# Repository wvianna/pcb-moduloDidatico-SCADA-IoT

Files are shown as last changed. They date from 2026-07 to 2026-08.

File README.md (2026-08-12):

# Projeto: PCB Módulo Didático SCADA/IoT

## Descrição do Projeto
Este projeto tem como objetivo fornecer uma plataforma de aprendizado para estudantes e entusiastas de automação industrial, sistemas SCADA e Internet das Coisas (IoT). A placa de circuito impresso (PCB) foi projetada para ser utilizada em laboratórios educacionais, permitindo a prática de conceitos teóricos em um ambiente controlado.

A PCB integra um **NodeMCU v2 (ESP8266)** com os seguintes componentes onboard:

- **Potenciômetro** — sinal analógico variável (simula sensor analógico)
- **Sensor DS18B20** — temperatura digital via 1-Wire
- **Driver de potência (transistor/resistência de aquecimento)** — carga controlada por PWM
- **Driver para servomotores** — canais PWM para azimute e elevação
- **Interface RS485 (MAX485)** — comunicação serial industrial half-duplex
- **Conectores para coils** — saídas digitais para relés ou buzzer
- **Conectores para entradas digitais** — contato seco ou switch onboard
- **LEDs de sinalização** — indicação visual de estado

---

> 🧩 **Projeto do firmware:** Este projeto foi desenvolvido para o firmware disponível em [github.com/wvianna/pcb-moduloDidatico-SCADA-IoT-firmware](https://github.com/wvianna/pcb-moduloDidatico-SCADA-IoT-firmware). O firmware gerencia todos os I/Os, sensores e interface RS485, implementando comunicação via **Modbus TCP/RTU**, **MQTT** e **OPC UA PubSub** — com seleção de protocolo via interface web.

---

**Autor:** William da Silva Vianna  
**Software Utilizado:** KiCad (v9 ou superior)

---

## 🧠 Visão Geral da Arquitetura

```mermaid
flowchart LR
  subgraph PCB["Placa PCB (Hardware)"]
    direction TB
    NODE[NodeMCU ESP8266]
    SEN[Sensores<br/>ADC + DS18B20]
    ATU[Atuadores<br/>Coils + PWM + Resistência]
    RS[RS485 MAX485]
    IN[Entradas Digitais]
  end

  subgraph FW["Firmware (software)"]
    REG[Modelo Interno<br/>de Registradores]
    PROT[Protocolo Ativo<br/>Modbus / MQTT / OPC UA]
    WEB[Servidor Web<br/>de Configuração]
  end

  subgraph EXT["Mundo Externo"]
    SCADA[SCADA / IHM]
    BRK[Broker MQTT]
    NRED[Node-RED]
  end

  NODE --> REG
  SEN --> REG
  REG --> ATU
  REG --> IN
  REG --> PROT
  WEB --> REG
  PROT --> SCADA
  PROT --> BRK
  PROT --> NRED
  RS -.-> SCADA
```

---

## � Pinout do NodeMCU

A imagem abaixo mostra a numeração dos pinos do **NodeMCU v2 (ESP8266)** utilizada no projeto. 
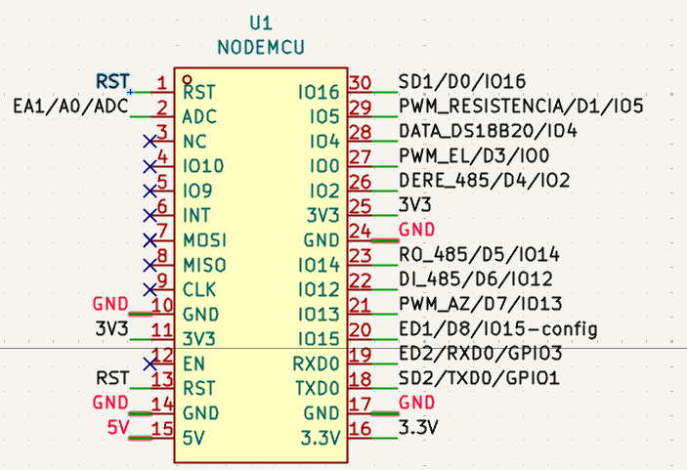
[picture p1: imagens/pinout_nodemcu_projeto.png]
Pinout NodeMCU v2 - Projeto


---

## �📋 Mapeamento de I/Os Físicos

A tabela abaixo relaciona cada funcionalidade da PCB ao pino do NodeMCU e ao registro Modbus correspondente. Este mapeamento é idêntico para todos os protocolos (Modbus, MQTT e OPC UA).

### Saídas Discretas (Coils)

| Endereço Modbus | Função | Pino NodeMCU | GPIO | Componente na PCB |
| ---: | --- | --- | --- | --- |
| 00001 | Saída discreta 1 | D0 | GPIO16 | Conector para relé/buzzer |
| 00002 | Saída discreta 2 | TX | GPIO1 | Conector para relé/buzzer |

### Entradas Discretas (Discrete Inputs)

| Endereço Modbus | Função | Pino NodeMCU | GPIO | Componente na PCB |
| ---: | --- | --- | --- | --- |
| 10001 | Entrada discreta 1 | D8 | GPIO15 | Switch onboard ou contato seco externo |
| 10002 | Entrada discreta 2 | RX | GPIO3 | Switch onboard ou contato seco externo |

> **Nota:** A entrada discreta 1 (ED1 / D8) também funciona como *boot pin* para forçar o modo de setup — basta colocá-la em nível baixo e reiniciar a placa.

### Entradas Analógicas (Input Registers)

| Endereço Modbus | Função | Pino NodeMCU | Faixa | Componente na PCB |
| ---: | --- | --- | ---: | --- |
| 30001 | ADC (potenciômetro) | A0 | 0..1023 | Potenciômetro onboard |
| 30002 | DS18B20 (temperatura) | D2 / GPIO4 | 0..1250 (x10 °C) | Sensor DS18B20 onboard |

### Saídas PWM (Holding Registers)

| Endereço Modbus | Função | Pino NodeMCU | GPIO | Faixa | Componente na PCB |
| ---: | --- | --- | --- | ---: | --- |
| 40001 | PWM azimute | D7 | GPIO13 | 0..1023 | Driver para servomotor |
| 40002 | PWM elevação | D3 | GPIO0 | 0..1023 | Driver para servomotor |
| 40003 | PWM resistência de aquecimento | D1 | GPIO5 | 0..1023 | Transistor + resistor de aquecimento onboard |

### Interface RS485 (Modbus RTU)

| Sinal MAX485 | Pino NodeMCU | GPIO |
| --- | --- | --- |
| RO (receptor) | D5 | GPIO14 |
| DI (driver) | D6 | GPIO12 |
| DE + RE (direção) | D4 | GPIO2 |

---
TIPO       |     DEVICE     | RANGE  |MODBUS
SD1        |BUZZER - PONTE H| 0 1    |COIL 00001
SD2        |RELE - PONTE H  | 0 1    |COIL 00002
PWM1       |SERVO - AZIMUTE | 0~1023 |H.R. 40001
PWM2       |SERVO - ELEVAÇÃO| 0~1023 |H.R. 40002
PMW3       |RESISTÊNCIA     | 0~1023 |H.R. 40003
ED1        |SW SECO - SETUP | 0 1    |D.I. 10001
ED2        |SW SECO         | 0 1    |D.I. 10002
EA0        |POTENCIÔMETRO   | 0~1023 |I.R. 30001
TEMPERATURA|DS18B20         | oC X 10|I.R. 30002
---

## 🔌 Diagrama de Blocos da PCB

```mermaid
flowchart TD
  subgraph PCB["PCB Módulo Didático SCADA/IoT"]
    MCU[NodeMCU ESP8266]

    subgraph ENTRADAS["Entradas"]
      POTE[Potenciômetro<br/>A0 / ADC]
      DS18[DS18B20<br/>D2 / 1-Wire]
      SW1[Switch ED1<br/>D8 / GPIO15]
      SW2[Switch ED2<br/>RX / GPIO3]
    end

    subgraph SAIDAS["Saídas"]
      C1[Coil 1<br/>D0 / GPIO16]
      C2[Coil 2<br/>TX / GPIO1]
      SRV1[Servo Azimute<br/>D7 / PWM]
      SRV2[Servo Elevação<br/>D3 / PWM]
      AQUE[Resistência<br/>D1 / PWM]
    end

    subgraph COMUM["Comunicação"]
      RS485[MAX485<br/>RS485 Half-Duplex]
    end

    subgraph SINAL["Sinalização"]
      LED[LED Config<br/>D4 / GPIO2]
    end

    MCU --- ENTRADAS
    MCU --- SAIDAS
    MCU --- RS485
    MCU --- SINAL
  end
```

---

## ⚡ Especificações Elétricas

| Parâmetro | Valor |
| --- | --- |
| Alimentação da placa | 5V DC (via USB ou conector) |
| Regulador onboard | 3,3V para o NodeMCU |
| Nível lógico dos GPIOs | 3,3V |
| Corrente máxima por GPIO | ~12 mA (com resistor de limitação) |
| Tensão no barramento RS485 | Diferencial (A/B) |
| Temperatura do DS18B20 | -55°C a +125°C |
| Faixa do ADC | 0..3,3V (10 bits, 0..1023) |

---

## 💻 Necessidade de Firmware

> ⚠️ **Nota Importante:** Este hardware **não é puramente analógico**. A placa foi projetada ao redor de uma arquitetura programável — o circuito impresso isolado não desempenha nenhuma função sem o respectivo **firmware**.

O firmware disponível em [pcb-moduloDidatico-SCADA-IoT-firmware](https://github.com/wvianna/pcb-moduloDidatico-SCADA-IoT-firmware) implementa:

1. **Inicialização (Setup):** Configuração dos registradores, direção dos pinos de I/O e taxas de transmissão dos barramentos.
2. **Loop principal cooperativo:** Leitura cíclica de sensores, atualização do modelo interno de registradores e aplicação nas saídas físicas — sem uso de `delay()` bloqueante.
3. **Servidor web de configuração:** Interface para definir SSID, IP, protocolo ativo (Modbus/MQTT/OPC UA) e parâmetros de comunicação, acessível via modo AP.
4. **Pilhas de comunicação:** Modbus TCP (porta 502), Modbus RTU (RS485), MQTT (PubSubClient) e OPC UA PubSub sobre MQTT.
5. **Persistência em LittleFS:** Configuração salva em arquivo texto na flash, com validação e fallback para valores padrão.

---

## 📁 Estrutura de Arquivos no Repositório

```text
├── esquema.pdf             # Diagrama esquemático exportado para leitura
├── meu-projeto.kicad_pro   # Arquivo de gerenciamento do projeto KiCad
├── meu-projeto.kicad_sch   # Folha do desenho esquemático
├── meu-projeto.kicad_pcb   # Layout da placa de circuito impresso
├── docs/
│   ├── mapeamentopinosmb.txt  # Mapa de pinos em formato CSV
│   └── requisitos.txt         # Requisitos elétricos e funcionais
├── firmware/                  # Submódulo do firmware
└── .gitignore              # Filtro de arquivos temporários do KiCad
```

---

## 🔗 Links Relacionados

| Recurso | Link |
| --- | --- |
| Repositório do firmware | [github.com/wvianna/pcb-moduloDidatico-SCADA-IoT-firmware](https://github.com/wvianna/pcb-moduloDidatico-SCADA-IoT-firmware) |
| Documentação do firmware | README do firmware |
| Esquema elétrico | `esquema.pdf` neste repositório |
| Mapa de pinos (CSV) | `docs/mapeamentopinosmb.txt` |

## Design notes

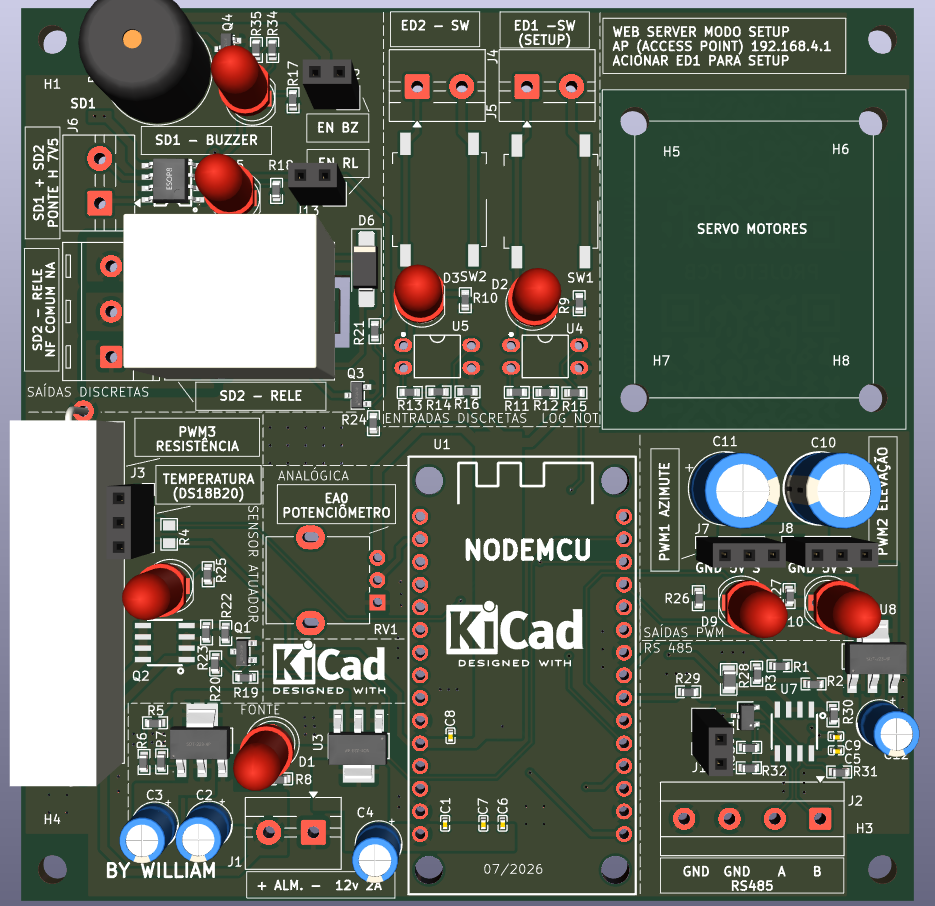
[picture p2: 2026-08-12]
imagens/pcbFront.png

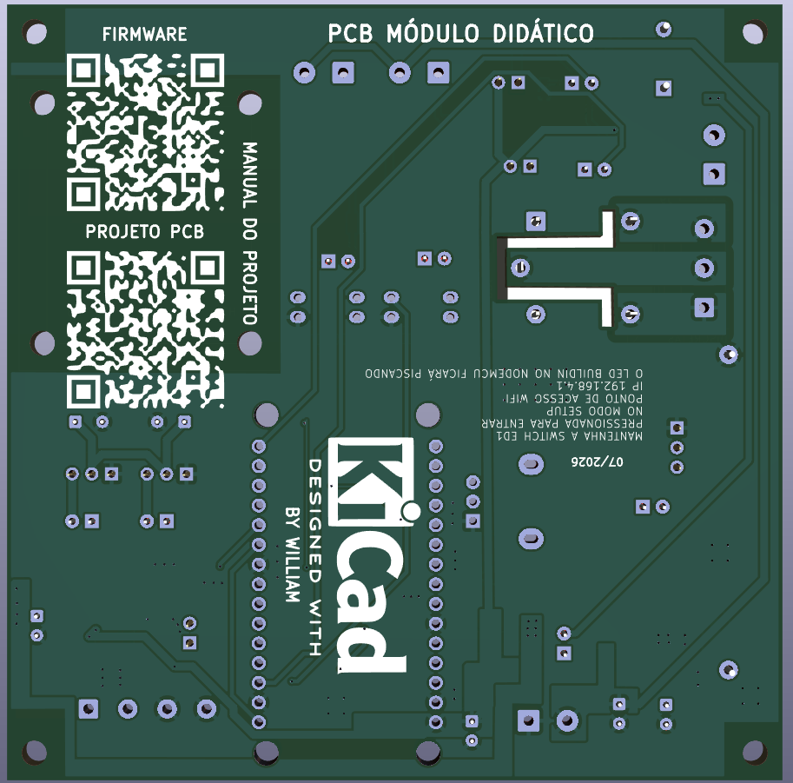
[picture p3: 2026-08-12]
imagens/pcbBack.png

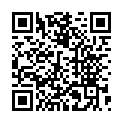
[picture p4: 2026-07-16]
imagens/qrfirmware.png

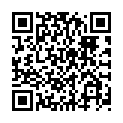
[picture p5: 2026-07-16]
imagens/qrpcb.png

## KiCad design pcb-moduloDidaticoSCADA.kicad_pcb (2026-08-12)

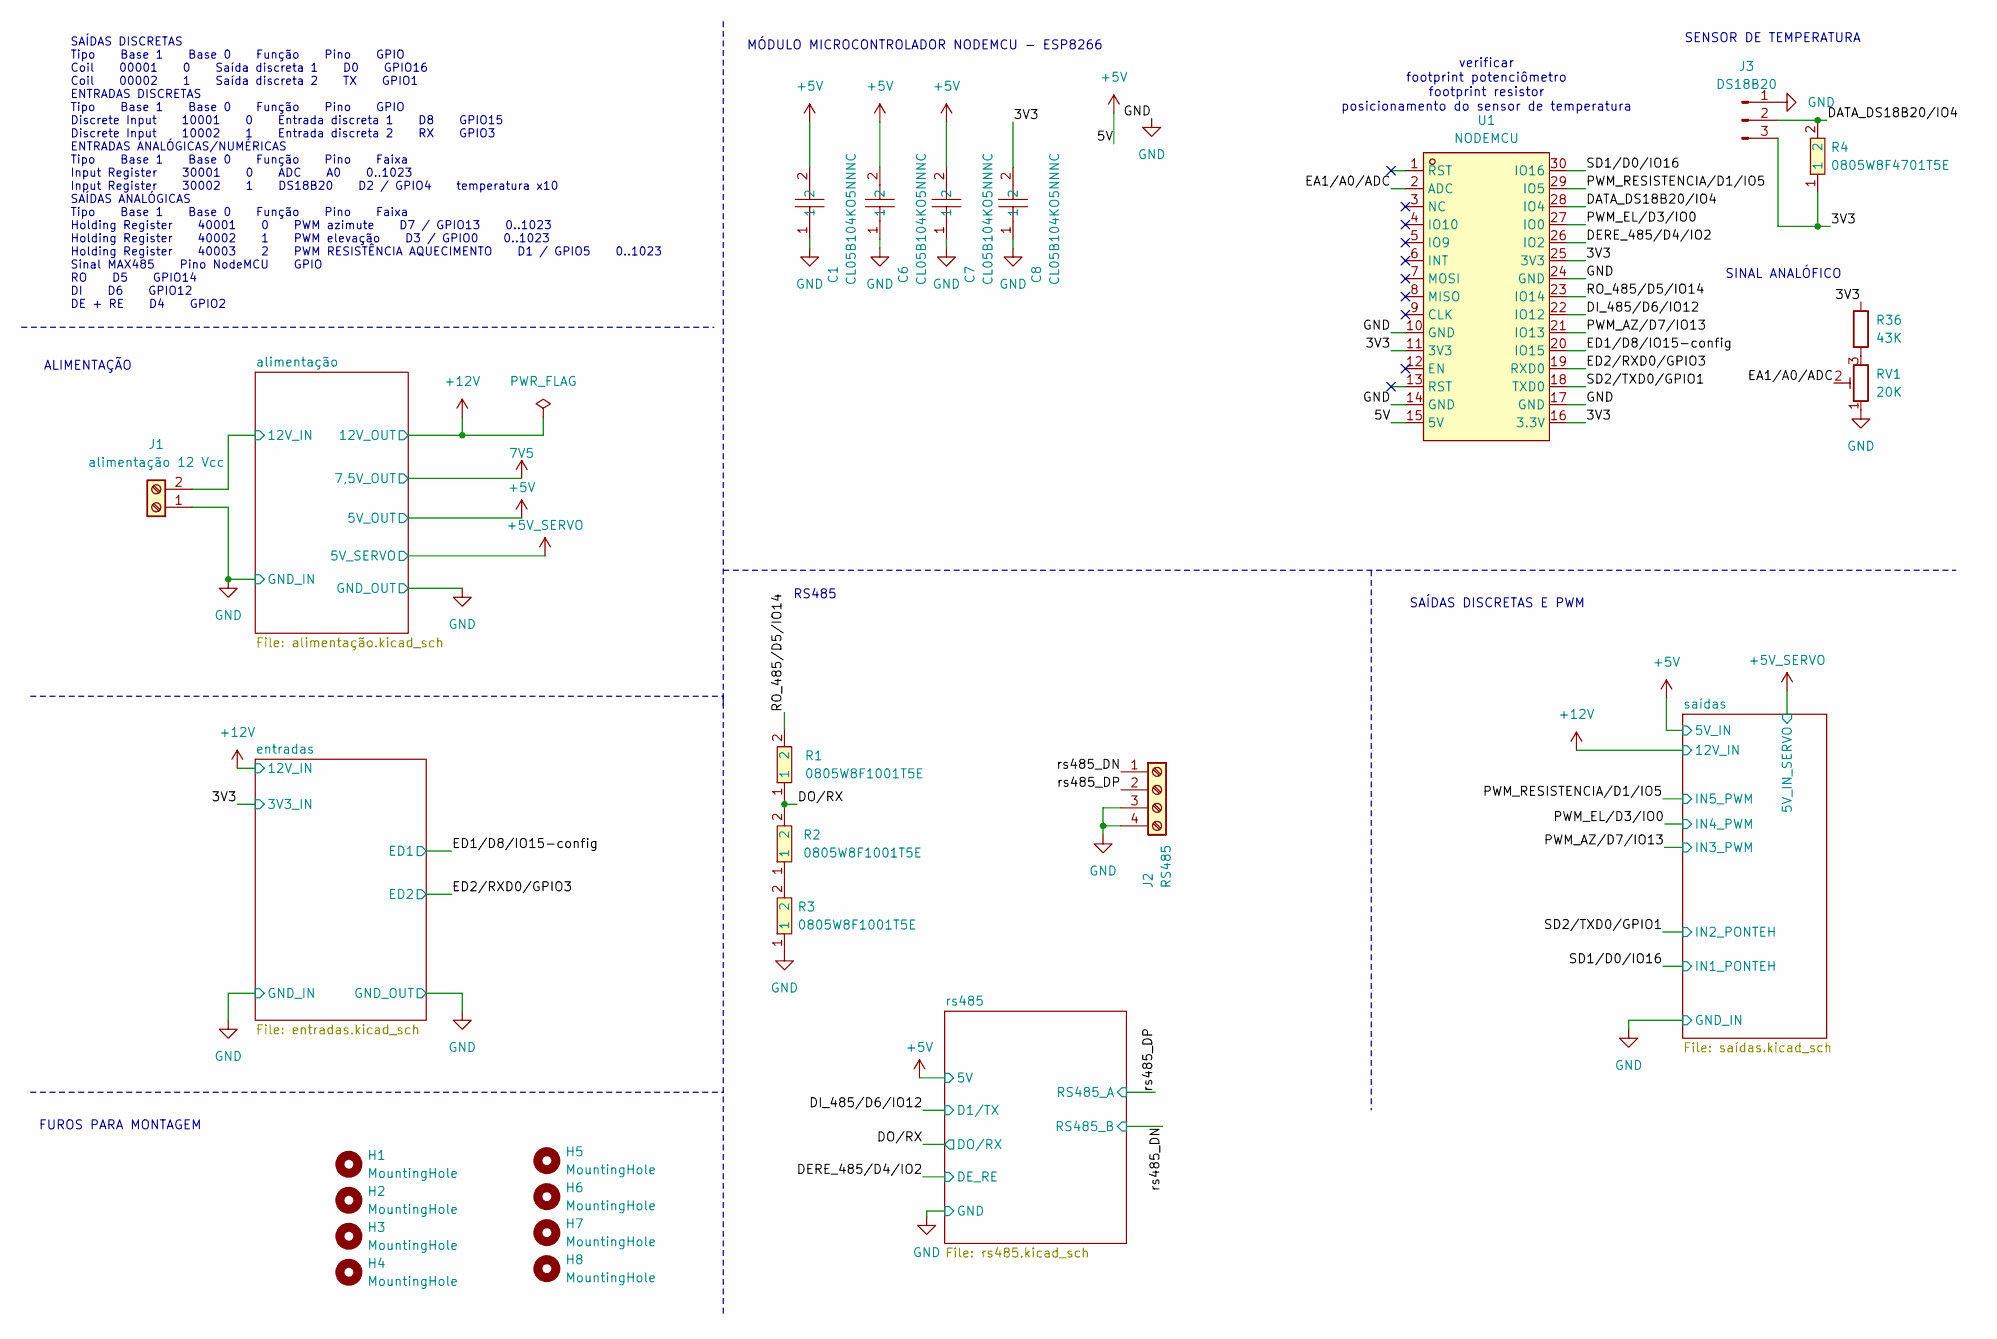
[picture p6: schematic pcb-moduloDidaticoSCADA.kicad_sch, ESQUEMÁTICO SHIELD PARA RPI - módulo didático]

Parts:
C1, C6, C7, C8: CL05B104KO5NNNC; C0402; MPN CL05B104KO5NNNC; LCSC Part C1525
H1, H2, H3, H4, H5, H6, H7, H8: MountingHole; MountingHole_3.2mm_M3
J1: alimentação 12 Vcc; TerminalBlock_MaiXu_MX126-5.0-02P_1x02_P5.00mm
J2: RS485; TerminalBlock_MetzConnect_Type101_RT01604HBWC_1x04_P5.08mm_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
J3: DS18B20; PinSocket_1x03_P2.54mm_Vertical
R1, R2, R3: 0805W8F1001T5E; R0805; MPN 0805W8F1001T5E; LCSC Part C17513
R4: 0805W8F4701T5E; R0805; LCSC Part C17673
R36: 43K; R_0805_2012Metric_Pad1.20x1.40mm_HandSolder
RV1: 20K; Potentiometer_Alpha_RD901F-40-00D_Single_Vertical
U1: NODEMCU; COMM-TH_NODEMCU-12F; MPN NODEMCU(12F); LCSC Part C2764098

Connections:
+5V: C1.2, C6.2, C7.2, U1.15 (5V); also elsewhere on the board
+12V: J1.2; also elsewhere on the board
/3V3: C8.2, J3.3, R4.1, R36.1, U1.11 (3V3), U1.16 (3.3V), U1.25 (3V3); also elsewhere on the board
/DATA_DS18B20/IO4: J3.2, R4.2, U1.28 (IO4)
/DERE_485/D4/IO2: U1.26 (IO2); also elsewhere on the board
/DI_485/D6/IO12: U1.22 (IO12); also elsewhere on the board
/DO/RX: R1.1, R2.2; also elsewhere on the board
/EA1/A0/ADC: RV1.2, U1.2 (ADC)
/ED1/D8/IO15-config: U1.20 (IO15); also elsewhere on the board
/ED2/RXD0/GPIO3: U1.19 (RXD0); also elsewhere on the board
/PWM_AZ/D7/IO13: U1.21 (IO13); also elsewhere on the board
/PWM_EL/D3/IO0: U1.27 (IO0); also elsewhere on the board
/PWM_RESISTENCIA/D1/IO5: U1.29 (IO5); also elsewhere on the board
/RO_485/D5/IO14: R1.2, U1.23 (IO14)
/SD1/D0/IO16: U1.30 (IO16); also elsewhere on the board
/SD2/TXD0/GPIO1: U1.18 (TXD0); also elsewhere on the board
/rs485_DN: J2.1; also elsewhere on the board
/rs485_DP: J2.2; also elsewhere on the board
GND: C1.1, C6.1, C7.1, C8.1, J1.1, J2.3, J2.4, J3.1, R3.1, RV1.1, U1.10 (GND), U1.14 (GND), U1.17 (GND), U1.24 (GND); also elsewhere on the board
unnamed: R2.1, R3.2
unnamed: R36.2, RV1.3

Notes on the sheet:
SENSOR DE TEMPERATURA
MÓDULO MICROCONTROLADOR NODEMCU - ESP8266
FUROS PARA MONTAGEM
SINAL ANALÓFICO
verificar footprint potenciômetro footprint resistor posicionamento do sensor de temperatura
ALIMENTAÇÃO
SAÍDAS DISCRETAS E PWM
RS485
SAÍDAS DISCRETAS Tipo Base 1 Base 0 Função Pino GPIO Coil 00001 0 Saída discreta 1 D0 GPIO16 Coil 00002 1 Saída discreta 2 TX GPIO1 ENTRADAS DISCRETAS Tipo Base 1 Base 0 Função Pino GPIO Discrete Input 10001 0 Entrada discreta 1 D8 GPIO15 Discrete Input 10002 1 Entrada discreta 2 RX GPIO3 ENTRADAS 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

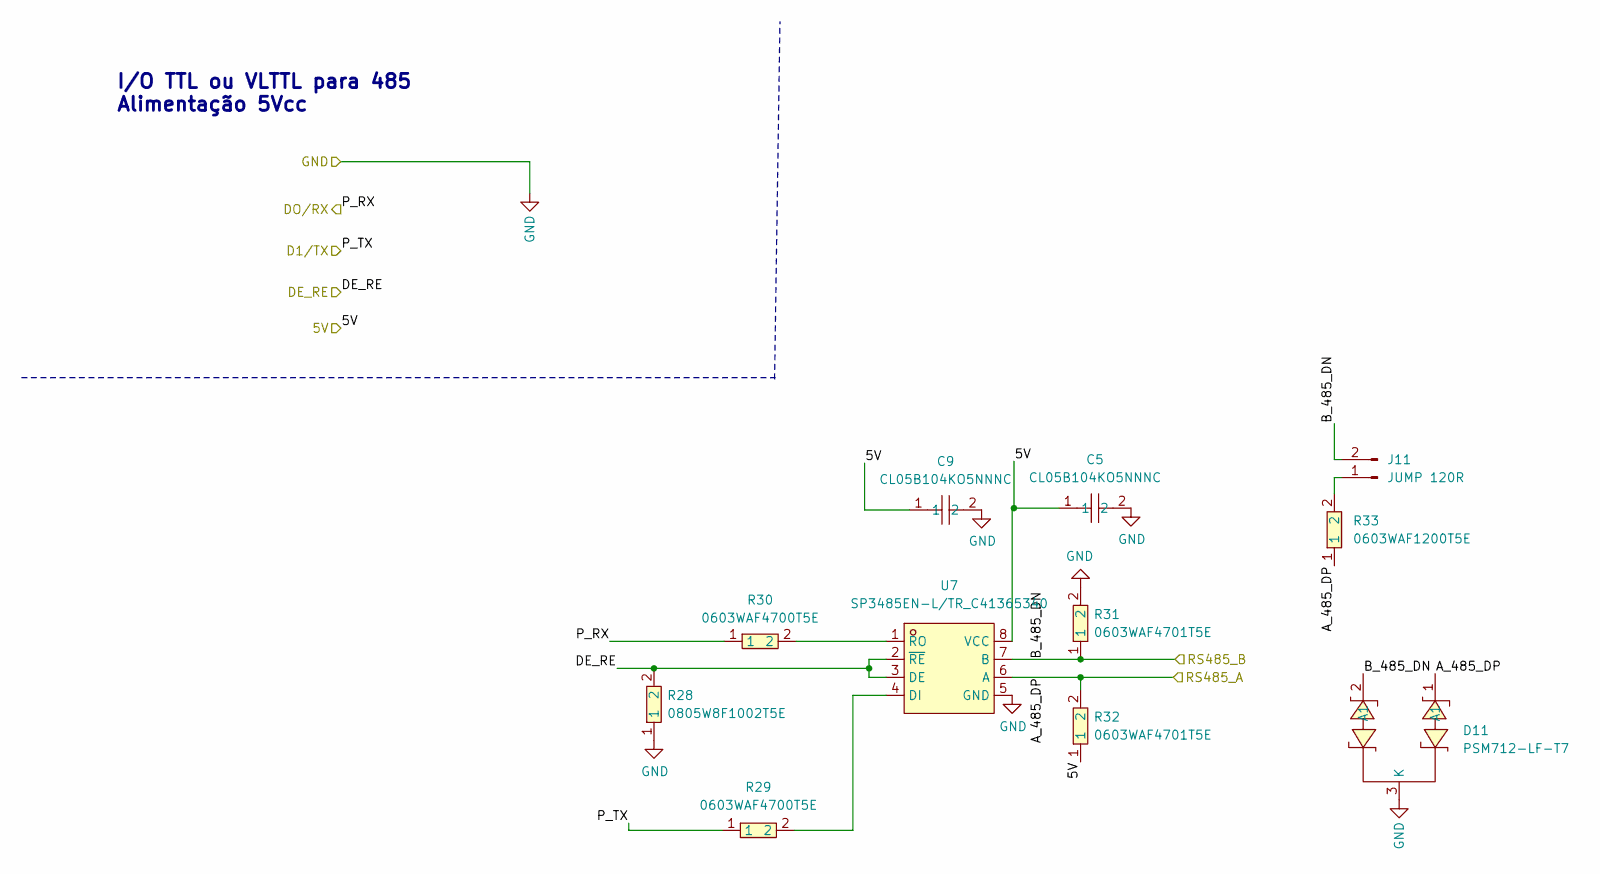
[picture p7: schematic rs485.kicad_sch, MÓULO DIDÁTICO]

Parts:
C5, C9: CL05B104KO5NNNC; C0402; MPN CL05B104KO5NNNC; LCSC Part C1525
D11: PSM712-LF-T7; SOT-23-3_L3.0-W1.7-P0.95-LS2.9-BR; MPN PSM712-LF-T7; LCSC Part C32677
J11: JUMP 120R; PinSocket_1x02_P2.54mm_Vertical
R28: 0805W8F1002T5E; R0805; MPN 0805W8F1002T5E; LCSC Part C17414
R29, R30: 0603WAF4700T5E; R0603; MPN 0603WAF4700T5E; LCSC Part C23179
R31, R32: 0603WAF4701T5E; R0603; MPN 0603WAF4701T5E; LCSC Part C23162
R33: 0603WAF1200T5E; R0603; MPN 0603WAF1200T5E; LCSC Part C22787
U7: SP3485EN-L/TR_C41365340; SO-8_L4.9-W3.9-P1.27-LS6.0-BL; MPN SP3485EN-L/TR; LCSC Part C41365340

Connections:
+5V: C5.1, C9.1, R32.1, U7.8 (VCC); also elsewhere on the board
/DERE_485/D4/IO2: R28.2, U7.2 (~RE), U7.3 (DE); also elsewhere on the board
/DI_485/D6/IO12: R29.1; also elsewhere on the board
/DO/RX: R30.1; also elsewhere on the board
/rs485_DN: D11.2 (A1), J11.2, R31.1, U7.7 (B); also elsewhere on the board
/rs485_DP: D11.1 (A1), R32.2, R33.1, U7.6 (A); also elsewhere on the board
GND: C5.2, C9.2, D11.3 (K), R28.1, R31.2, U7.5 (GND); also elsewhere on the board
unnamed: J11.1, R33.2
unnamed: R29.2, U7.4 (DI)
unnamed: R30.2, U7.1 (RO)

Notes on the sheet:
I/O TTL ou VLTTL para 485 Alimentação 5Vcc

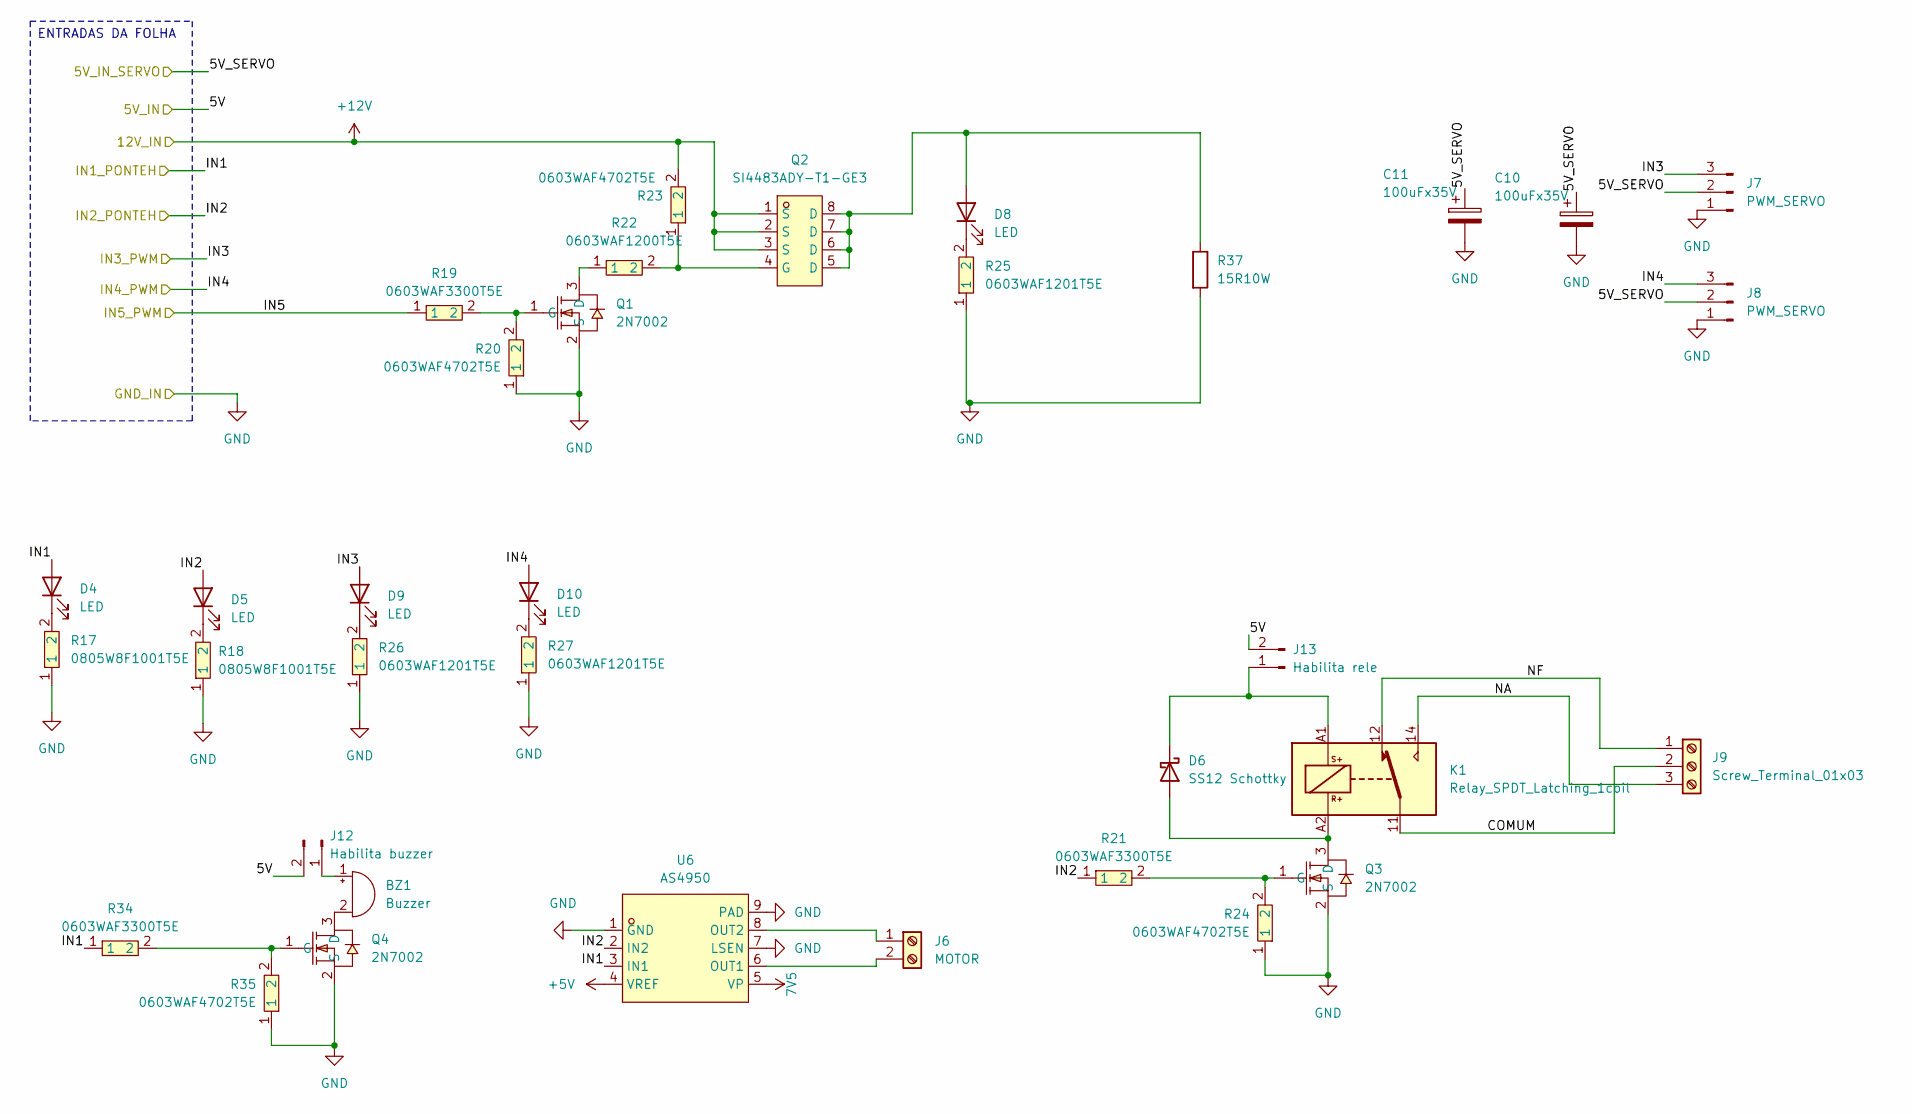
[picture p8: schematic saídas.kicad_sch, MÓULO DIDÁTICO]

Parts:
BZ1: Buzzer; Buzzer_12x9.5RM7.6
C10, C11: 100uFx35V; CP_Radial_D8.0mm_P3.50mm
D4, D5, D8, D9, D10: LED; LED_D5.0mm
D6: SS12 Schottky; D_SMA_Handsoldering
J6: MOTOR; TerminalBlock_MaiXu_MX126-5.0-02P_1x02_P5.00mm
J7, J8: PWM_SERVO; PinSocket_1x03_P2.54mm_Vertical
J9: Screw_Terminal_01x03; TerminalBlock_RND_205-00288_1x03_P5.08mm_Horizontal
J12: Habilita buzzer; PinSocket_1x02_P2.54mm_Vertical
J13: Habilita rele; PinSocket_1x02_P2.54mm_Vertical
K1: Relay_SPDT_Latching_1coil; Relay_SPDT_Finder_36.11
Q1, Q3, Q4: 2N7002; SOT-23-3_L2.9-W1.3-P1.90-LS2.4-BR; MPN 2N7002; LCSC Part C8545
Q2: SI4483ADY-T1-GE3; SO-8_L4.9-W3.9-P1.27-LS6.0-BL; LCSC Part C727843
R17, R18: 0805W8F1001T5E; R0805; MPN 0805W8F1001T5E; LCSC Part C17513
R19, R21, R34: 0603WAF3300T5E; R0603; MPN 0603WAF3300T5E; LCSC Part C23138
R20, R23, R24, R35: 0603WAF4702T5E; R0603; MPN 0603WAF4702T5E; LCSC Part C25819
R22: 0603WAF1200T5E; R0603; MPN 0603WAF1200T5E; LCSC Part C22787
R25, R26, R27: 0603WAF1201T5E; R0603; MPN 0603WAF1201T5E; LCSC Part C22765
R37: 15R10W; R_Axial_Power_L38.0mm_W9.0mm_P40.64mm
U6: AS4950; ESOP-8_L4.9-W3.9-P1.27-LS6.0-BL-EP; MPN AS4950; LCSC Part C2929412

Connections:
7V5: U6.5 (VP); also elsewhere on the board
+5V: J12.2, J13.2, U6.4 (VREF); also elsewhere on the board
+5V_SERVO: C10.1, C11.1, J7.2, J8.2; also elsewhere on the board
+12V: Q2.1 (S), Q2.2 (S), Q2.3 (S), R23.2; also elsewhere on the board
/PWM_AZ/D7/IO13: D9.2 (A), J7.3; also elsewhere on the board
/PWM_EL/D3/IO0: D10.2 (A), J8.3; also elsewhere on the board
/PWM_RESISTENCIA/D1/IO5: R19.1; also elsewhere on the board
/SD1/D0/IO16: D4.2 (A), R34.1, U6.3 (IN1); also elsewhere on the board
/SD2/TXD0/GPIO1: D5.2 (A), R21.1, U6.2 (IN2); also elsewhere on the board
/saídas/COMUM: J9.2, K1.11
/saídas/NA: J9.3, K1.14
/saídas/NF: J9.1, K1.12
GND: C10.2, C11.2, J7.1, J8.1, Q1.2 (S), Q3.2 (S), Q4.2 (S), R17.1, R18.1, R20.1, R24.1, R25.1, R26.1, R27.1, R35.1, R37.2, U6.1 (GND), U6.7 (LSEN), U6.9 (PAD); also elsewhere on the board
unnamed: BZ1.1 (+), J12.1
unnamed: BZ1.2 (-), Q4.3 (D)
unnamed: D4.1 (K), R17.2
unnamed: D5.1 (K), R18.2
unnamed: D6.2 (A), K1.A2, Q3.3 (D)
unnamed: D6.1 (K), J13.1, K1.A1
unnamed: D8.2 (A), Q2.5 (D), Q2.6 (D), Q2.7 (D), Q2.8 (D), R37.1
unnamed: D8.1 (K), R25.2
unnamed: D9.1 (K), R26.2
unnamed: D10.1 (K), R27.2
unnamed: J6.1, U6.8 (OUT2)
unnamed: J6.2, U6.6 (OUT1)
unnamed: Q1.3 (D), R22.1
unnamed: Q1.1 (G), R19.2, R20.2
unnamed: Q2.4 (G), R22.2, R23.1
unnamed: Q3.1 (G), R21.2, R24.2
unnamed: Q4.1 (G), R34.2, R35.2

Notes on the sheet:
ENTRADAS DA FOLHA

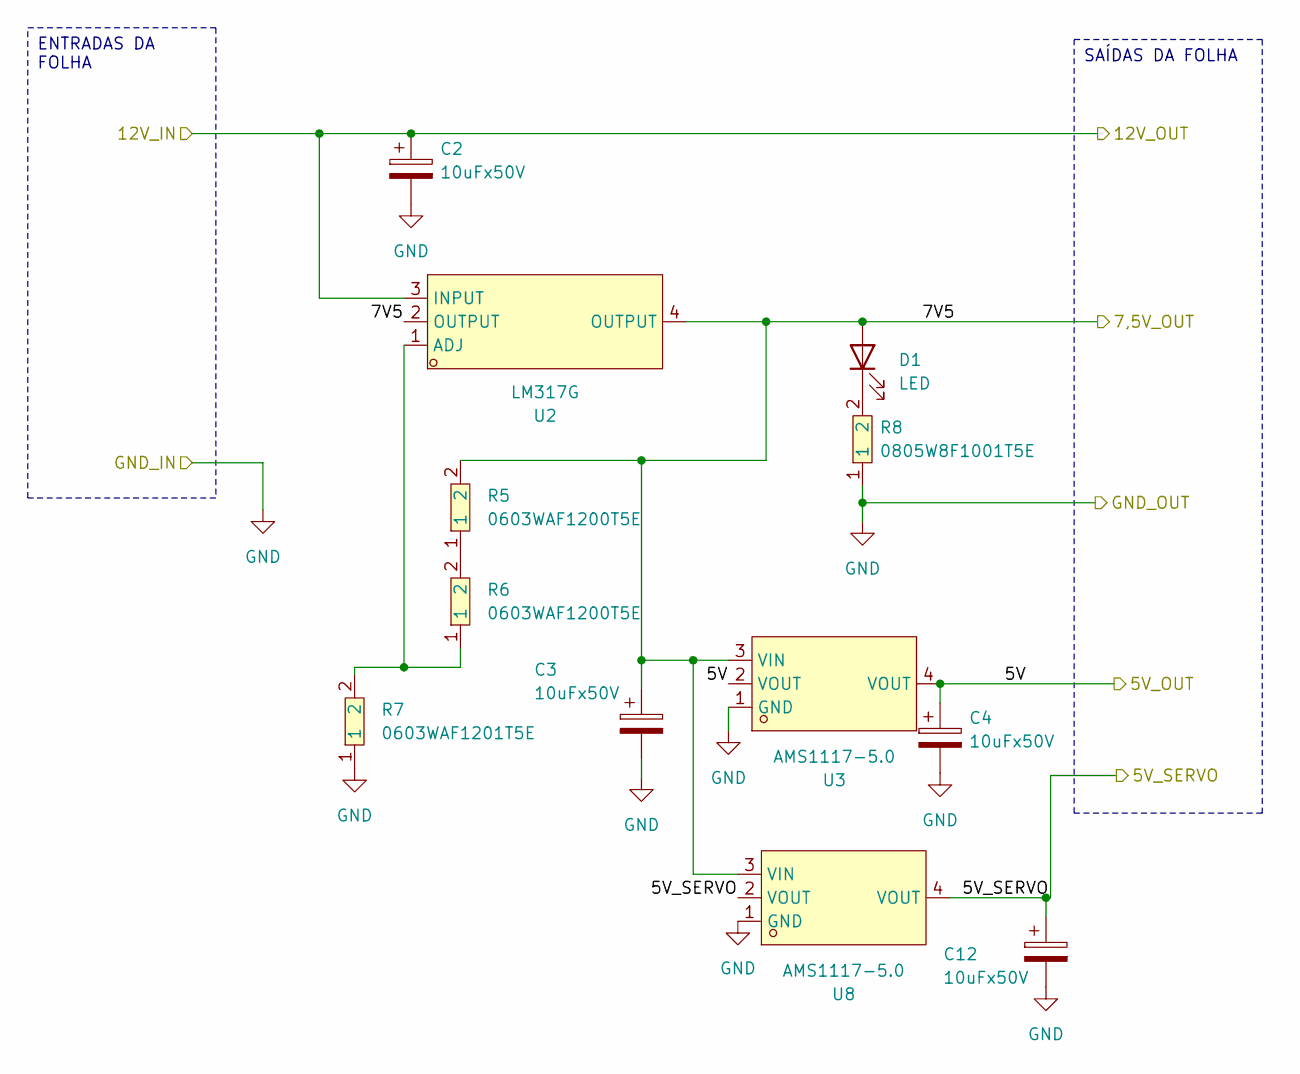
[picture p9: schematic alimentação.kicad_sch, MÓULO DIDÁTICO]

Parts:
C2, C3, C4, C12: 10uFx50V; CP_Radial_D5.0mm_P2.50mm
D1: LED; LED_D5.0mm
R5, R6: 0603WAF1200T5E; R0603; MPN 0603WAF1200T5E; LCSC Part C22787
R7: 0603WAF1201T5E; R0603; MPN 0603WAF1201T5E; LCSC Part C22765
R8: 0805W8F1001T5E; R0805; MPN 0805W8F1001T5E; LCSC Part C17513
U2: LM317G; SOT-223_L6.5-W3.5-P2.30-LS7.0-BR; MPN LM317G; LCSC Part C347367
U3, U8: AMS1117-5.0; SOT-223_L6.5-W3.5-P2.30-LS7.0-BR; MPN AMS1117-5.0; LCSC Part C6187

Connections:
7V5: C3.1, D1.2 (A), R5.2, U2.2 (OUTPUT), U2.4 (OUTPUT), U3.3 (VIN), U8.3 (VIN); also elsewhere on the board
+5V: C4.1, U3.2 (VOUT), U3.4 (VOUT); also elsewhere on the board
+5V_SERVO: C12.1, U8.2 (VOUT), U8.4 (VOUT); also elsewhere on the board
+12V: C2.1, U2.3 (INPUT); also elsewhere on the board
GND: C2.2, C3.2, C4.2, C12.2, R7.1, R8.1, U3.1 (GND), U8.1 (GND); also elsewhere on the board
unnamed: D1.1 (K), R8.2
unnamed: R5.1, R6.2
unnamed: R6.1, R7.2, U2.1 (ADJ)

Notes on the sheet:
ENTRADAS DA FOLHA
SAÍDAS DA FOLHA

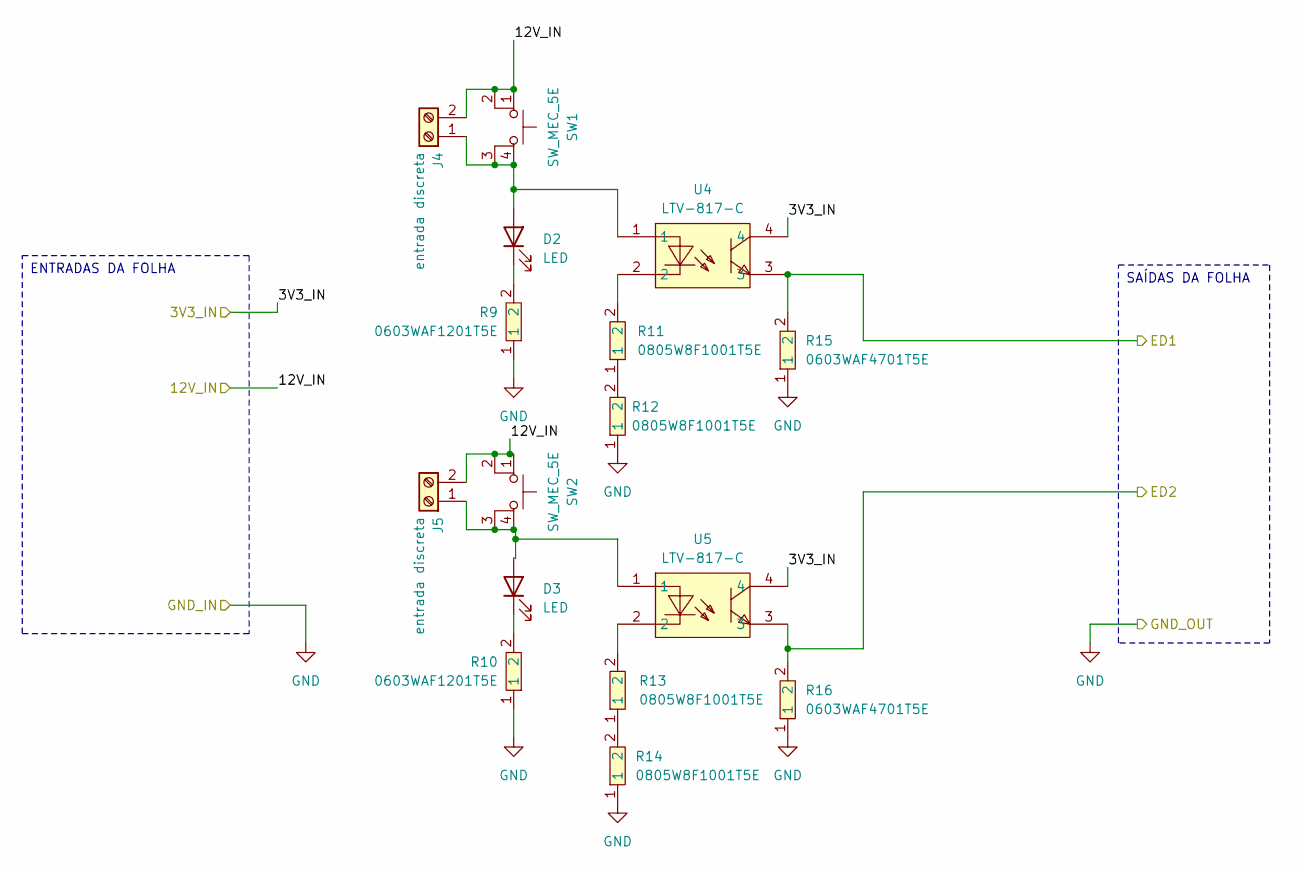
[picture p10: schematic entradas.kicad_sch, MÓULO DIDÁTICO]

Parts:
D2, D3: LED; LED_D5.0mm
J4, J5: entrada discreta; TerminalBlock_MaiXu_MX126-5.0-02P_1x02_P5.00mm
R9, R10: 0603WAF1201T5E; R0603; MPN 0603WAF1201T5E; LCSC Part C22765
R11, R12, R13, R14: 0805W8F1001T5E; R0805; MPN 0805W8F1001T5E; LCSC Part C17513
R15, R16: 0603WAF4701T5E; R0603; MPN 0603WAF4701T5E; LCSC Part C23162
SW1, SW2: SW_MEC_5E; SW_MEC_5GSH9
U4, U5: LTV-817-C; DIP-4_L4.6-W6.5-P2.54-LS7.6-BL

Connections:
+12V: J4.2, J5.2, SW1.1, SW1.2, SW2.1, SW2.2; also elsewhere on the board
/3V3: U4.4, U5.4; also elsewhere on the board
/ED1/D8/IO15-config: R15.2, U4.3; also elsewhere on the board
/ED2/RXD0/GPIO3: R16.2, U5.3; also elsewhere on the board
GND: R9.1, R10.1, R12.1, R14.1, R15.1, R16.1; also elsewhere on the board
unnamed: D2.2 (A), J4.1, SW1.3 (K), SW1.4 (A), U4.1
unnamed: D2.1 (K), R9.2
unnamed: D3.2 (A), J5.1, SW2.3 (K), SW2.4 (A), U5.1
unnamed: D3.1 (K), R10.2
unnamed: R11.1, R12.2
unnamed: R11.2, U4.2
unnamed: R13.1, R14.2
unnamed: R13.2, U5.2

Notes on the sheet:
ENTRADAS DA FOLHA
SAÍDAS DA FOLHA

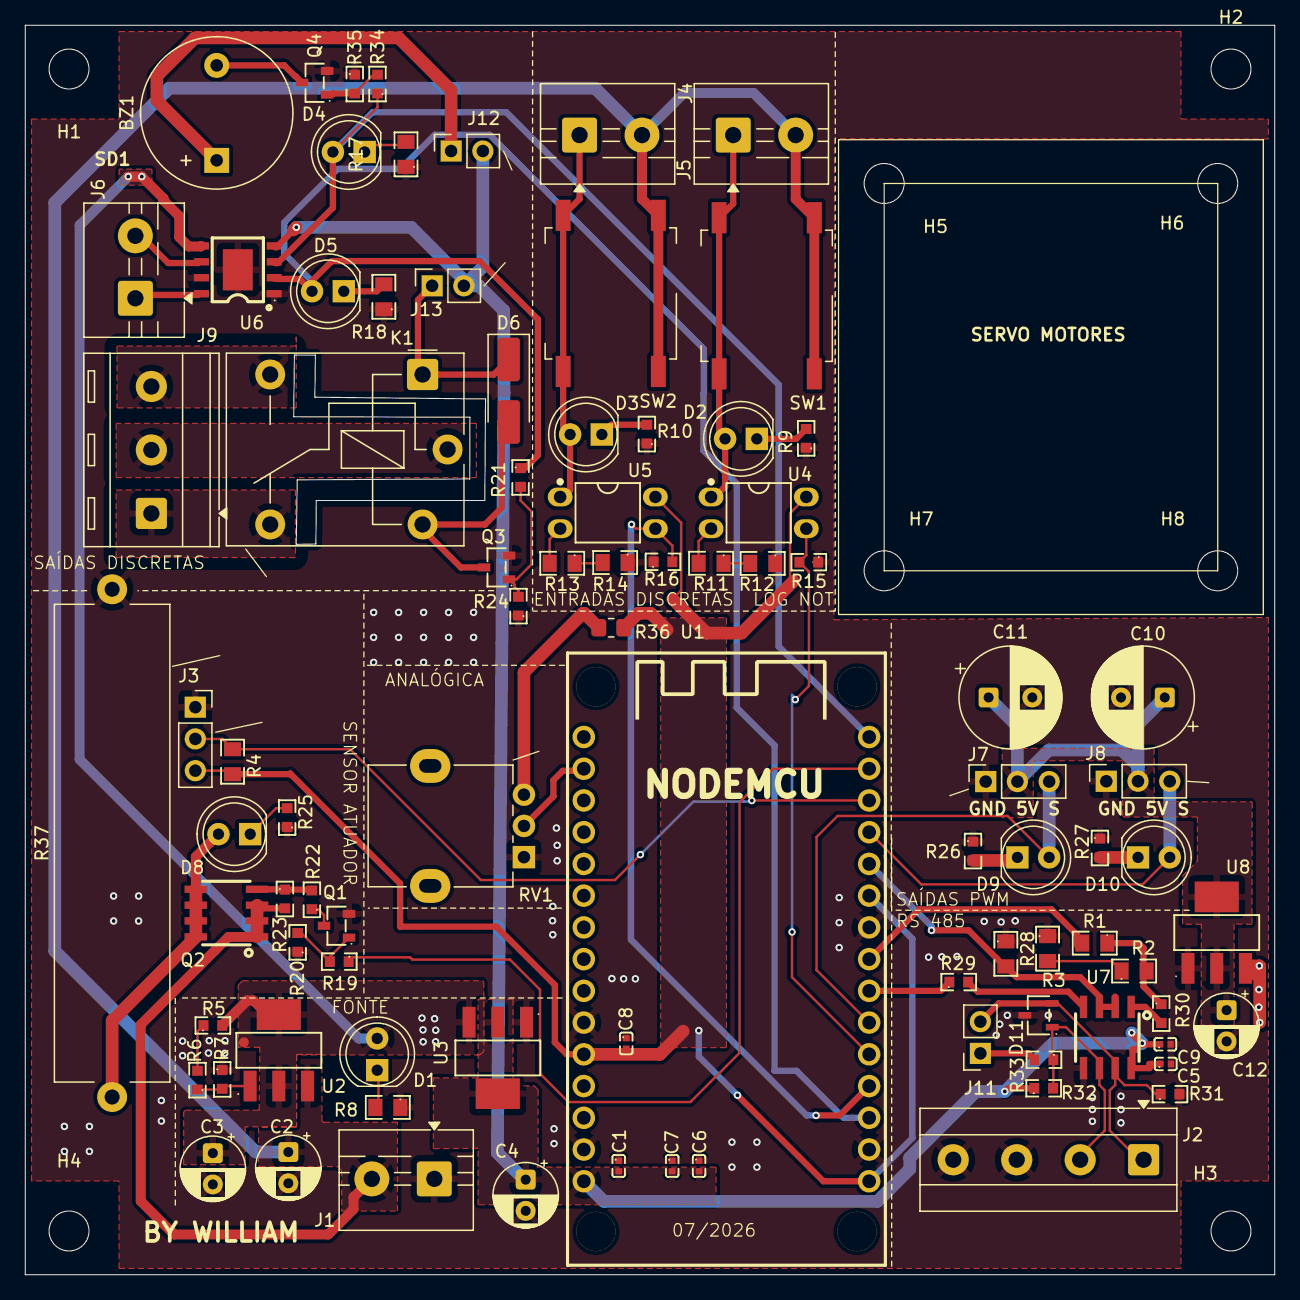
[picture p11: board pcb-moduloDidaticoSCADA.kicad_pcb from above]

Board: 2 copper layers, 100.0 x 100.0 mm, 96 parts (0 on the bottom side), 57 nets.

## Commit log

2026-07-13 Initial commit: Projeto KiCad
    [alimentação.kicad_sch, entradas.kicad_sch, pcb-moduloDidaticoSCADA.kicad_pcb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]
2026-07-13 readme atualizado
    [pcb-moduloDidaticoSCADA.kicad_sch]
2026-07-13 organização e legendas do esquemático
    [alimentação.kicad_sch, entradas.kicad_sch, pcb-moduloDidaticoSCADA.kicad_sch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]
2026-07-15 style: ajustes no layout
    [pcb-moduloDidaticoSCADA.kicad_pcb, pcb-moduloDidaticoSCADA.kicad_sch, saídas.kicad_sch]
2026-07-16 ajustes no layout e serigrafia
    [alimentação.kicad_sch, pcb-moduloDidaticoSCADA.kicad_pcb, pcb-moduloDidaticoSCADA.kicad_sch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]
2026-07-16 inclusão de zip no gitignore
2026-08-12 ajusta circuitos de entrada, alimentação e saída e adiciona visualizações da PCB
    [alimentação.kicad_sch, entradas.kicad_sch, pcb-moduloDidaticoSCADA.kicad_pcb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]
